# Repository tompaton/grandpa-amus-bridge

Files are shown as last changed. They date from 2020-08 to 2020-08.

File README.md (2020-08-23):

## grandpa-amus-bridge

Model of the traditional Chinese bridge constructed by Grandpa Amu

# Grandpa Amu's Bridge

I found this traditional Chinese bridge design and construction
captivating.  The interlocking pieces mean that no fasteners or glue
is required and it gets stronger under load.

[Construction video](https://www.youtube.com/watch?v=PYkgEf3eWqA) and
[more, because who can get enough?](https://www.youtube.com/watch?v=iSPAK3mcI3c)

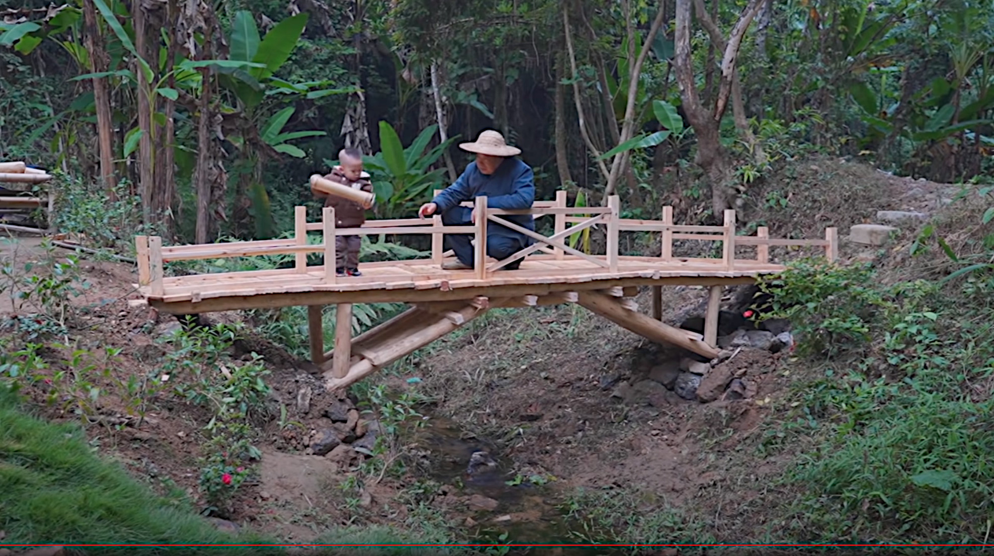
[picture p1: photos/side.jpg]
Bridge from the side


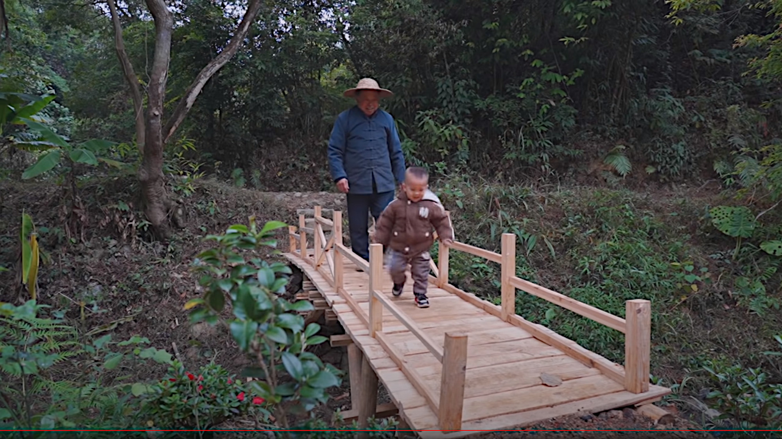
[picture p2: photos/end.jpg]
Bridge from the emd


## CAD model

First I created a CAD model using
[DeclaraCAD](https://declaracad.com/).

[bridge.enaml source](https://github.com/tompaton/grandpa-amus-bridge/blob/master/src/bridge.enaml)

This worked pretty well as there are lots of repeated parts, and by
using the `Cut` operation, mortises could be automatically created in
exactly the right locations for the tenons.

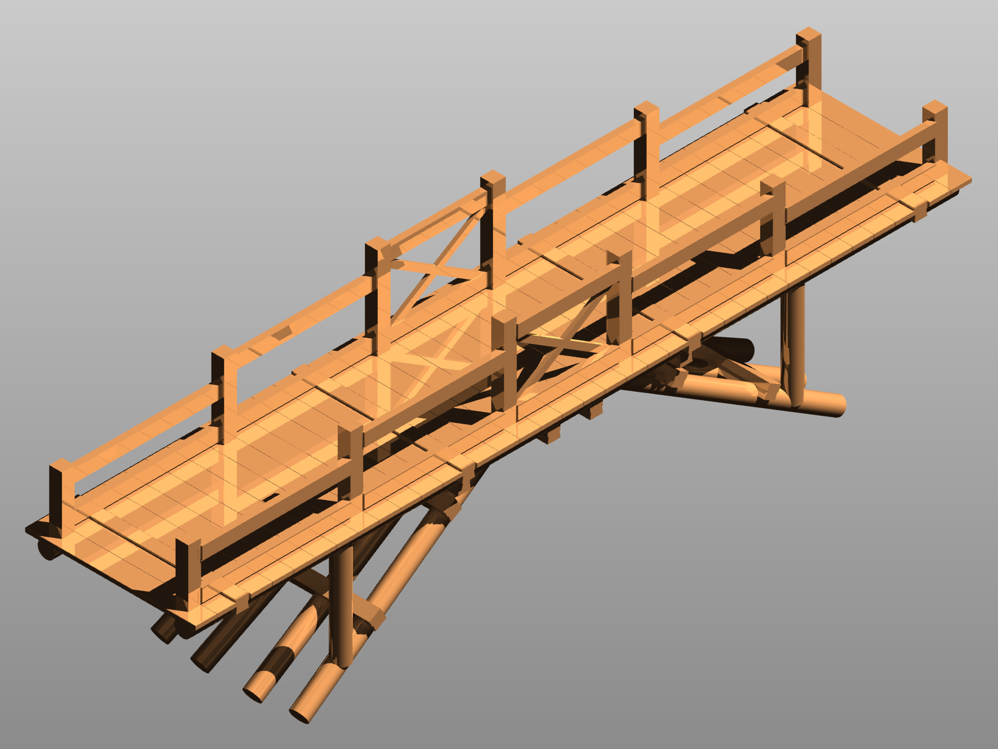
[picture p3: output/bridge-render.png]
Rendered CAD model


Transparency helps see the structure and joints:

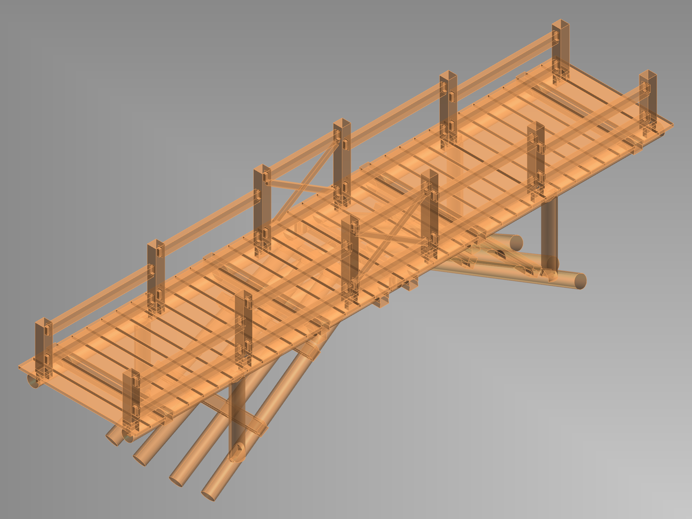
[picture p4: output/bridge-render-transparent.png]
Transparent render


I was able to export a [bridge.step](output/bridge.step) file which
could be imported into [FreeCAD](https://www.freecadweb.org/) to
generate a drawing.

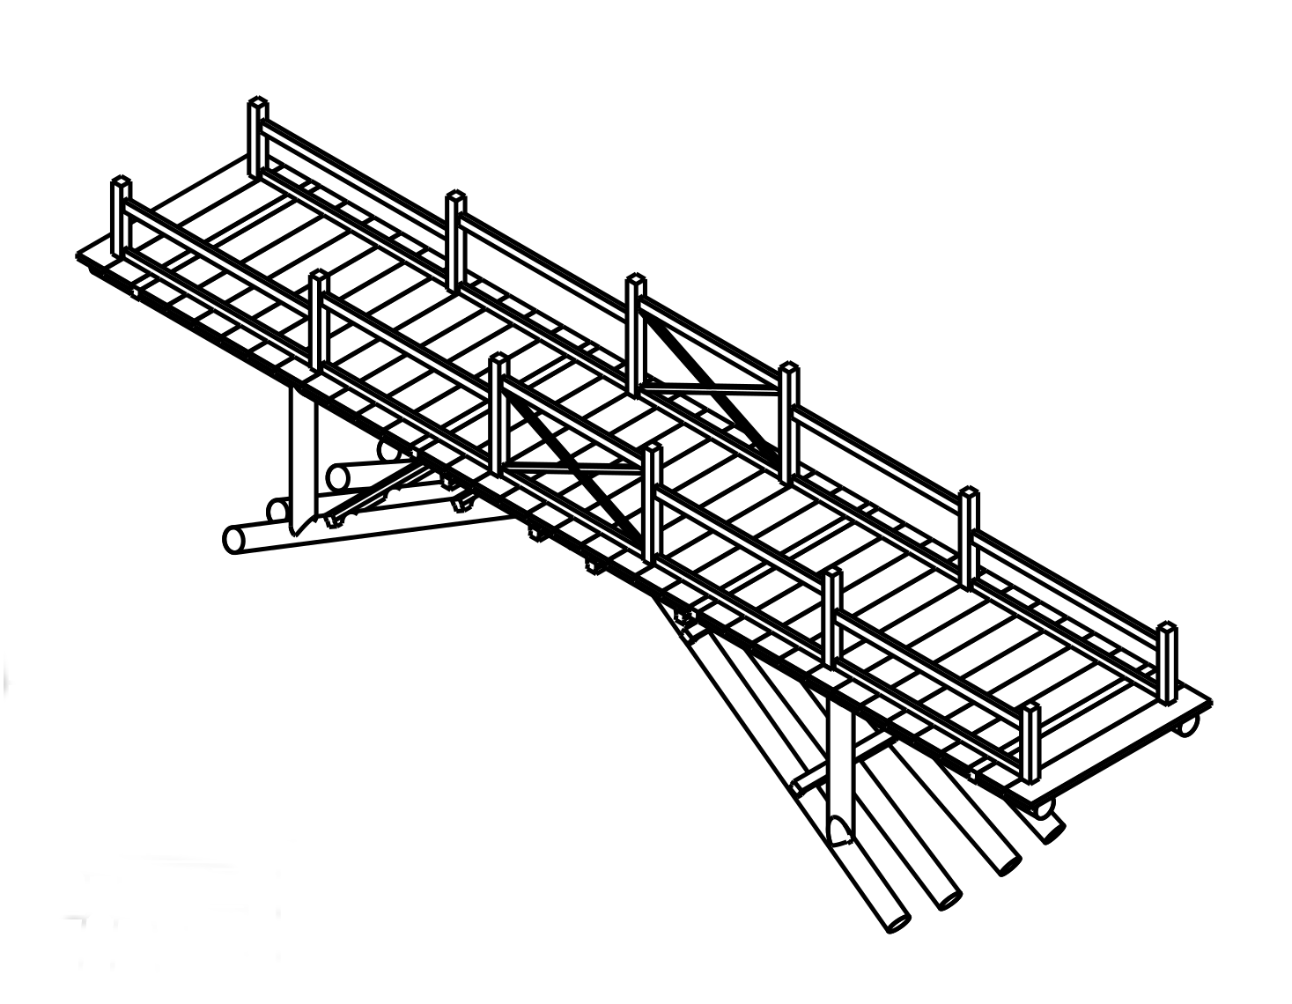
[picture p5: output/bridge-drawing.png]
Technical drawing detail


[Full page drawing](output/bridge-drawing.pdf) with other elevation views.

And after converting that to
[bridge.stl](https://github.com/tompaton/grandpa-amus-bridge/blob/master/output/bridge.stl)
it should be viewable in 3D everywhere.

## Scale model

Even though I created the CAD model and drawings, construction was
done by eye.

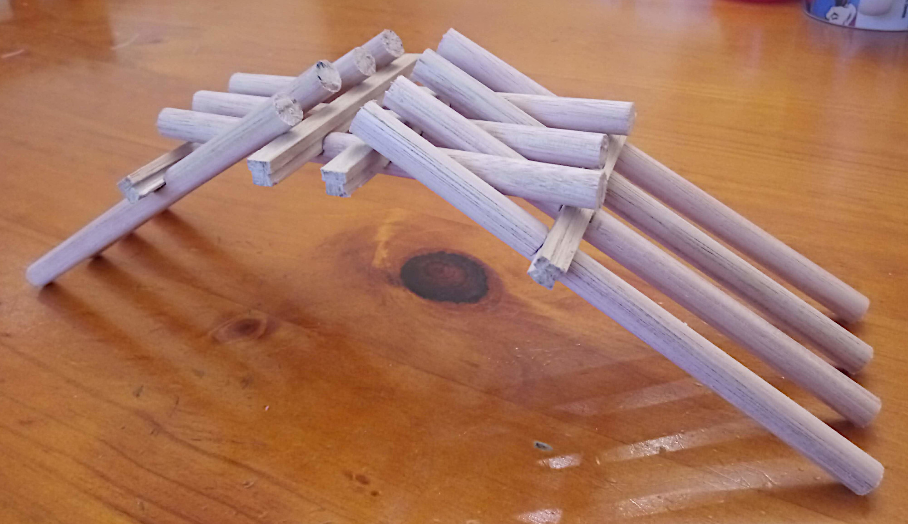
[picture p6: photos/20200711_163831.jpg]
First steps

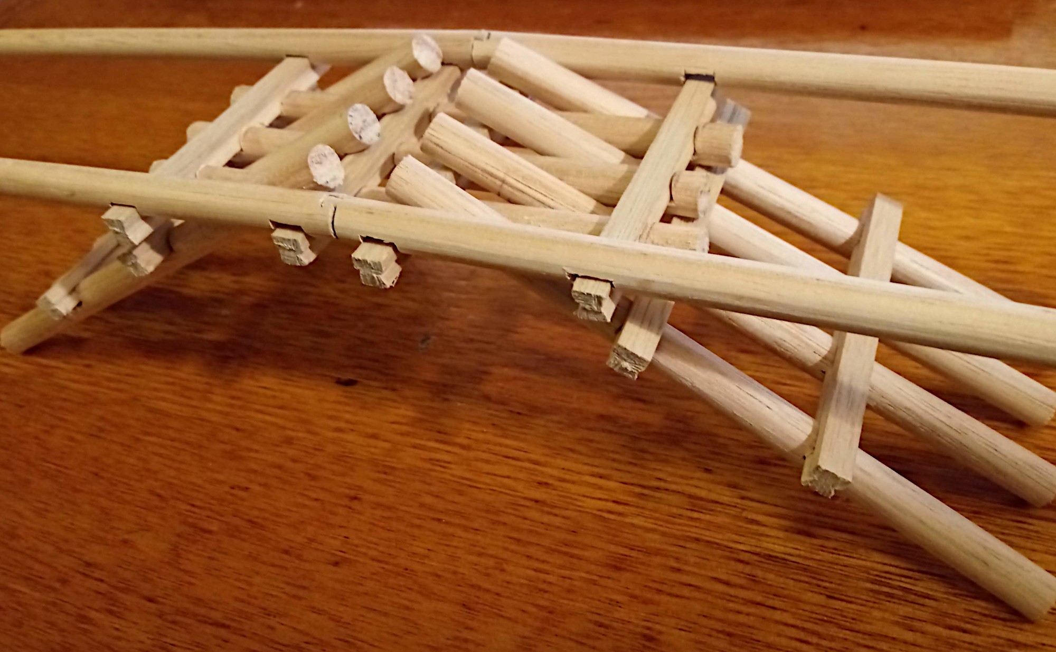
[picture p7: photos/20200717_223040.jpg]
Base structure

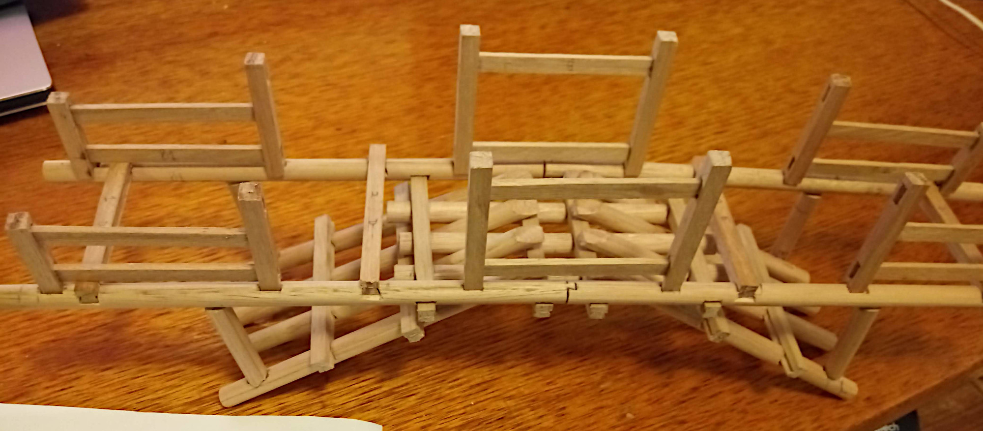
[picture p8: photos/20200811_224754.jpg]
Side rails

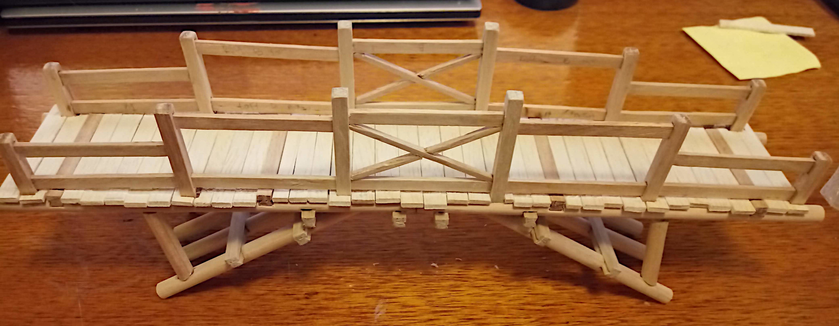
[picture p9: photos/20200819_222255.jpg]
Final assembly


The final model would hold together without glue, but it's a bit
fragile that way and I've spent enough time assembling it, so I glued
it with PVA craft glue.

It was then finished with a few coats of shellac.

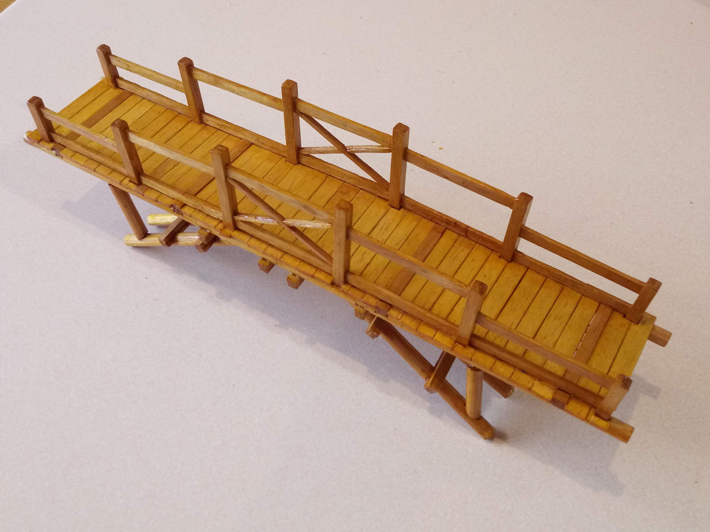
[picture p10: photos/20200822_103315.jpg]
Finished bridge model

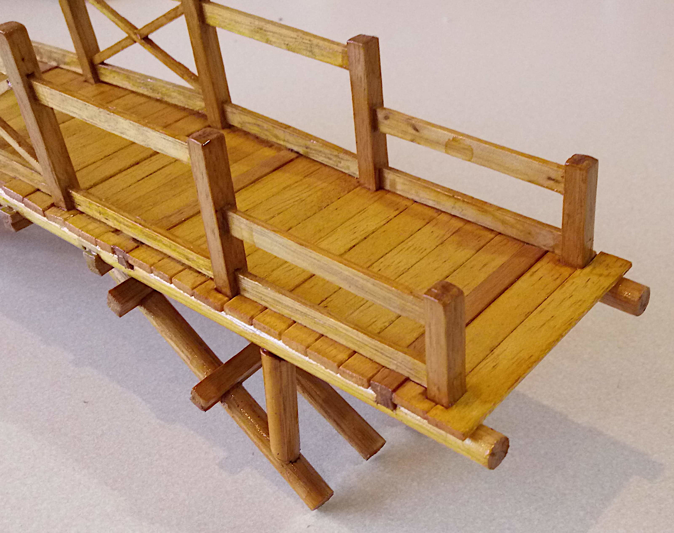
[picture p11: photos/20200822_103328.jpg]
Detail

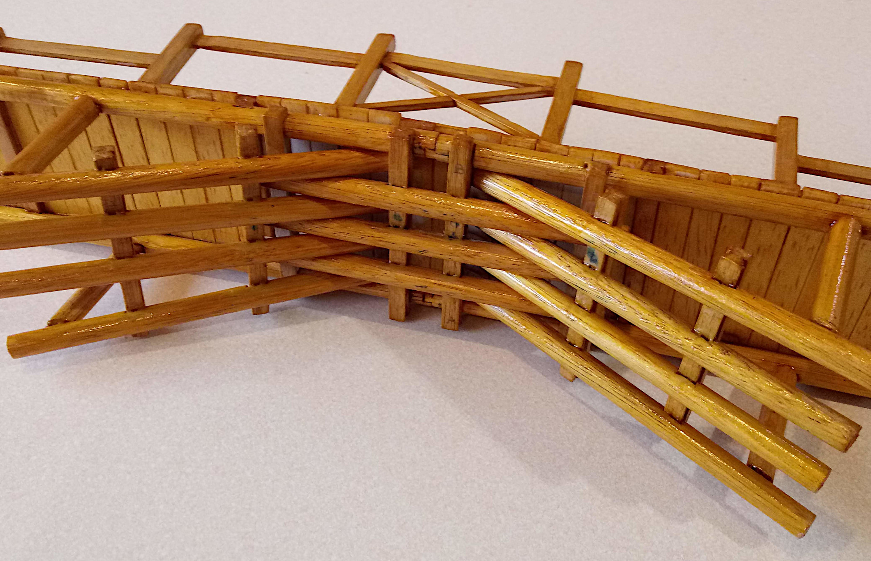
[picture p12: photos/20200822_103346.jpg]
Underside detail


### Tools & Materials

* Craft knife
* Mini-hacksaw
* Sandpaper

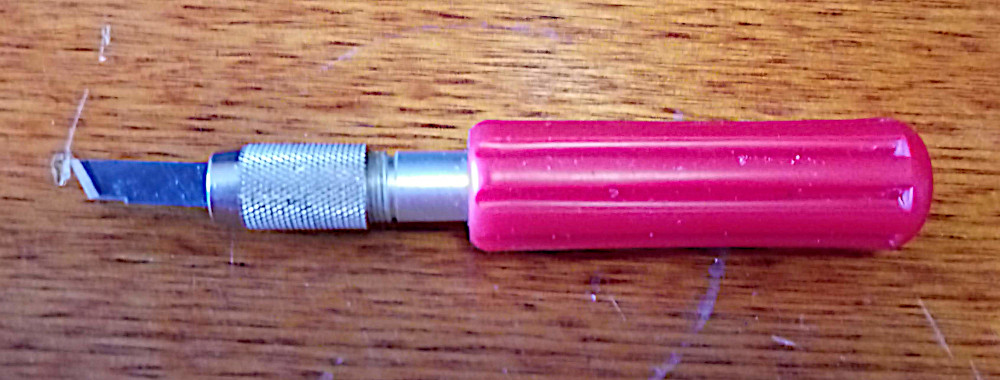
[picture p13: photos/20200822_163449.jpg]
Craft knife


* 8mm x 1200mm Tasmanian oak round dowel (2 pieces)
* 6mm x 6mm x 1200mm Tasmanian oak dressed all round moulding (2 pieces)
* 2.5mm x 100mm x 915mm balsa sheet (1/3 of a piece)

I cut mortises with the craft knife when it would have been more
sensible to make a jig to drill out mortise holes.

Rails were created by splitting the square dowel.

There wasn't much waste, probably about 20mm left from each of the
round and square dowels.

## Next steps?

* 3D printed plastic model
* Paper model

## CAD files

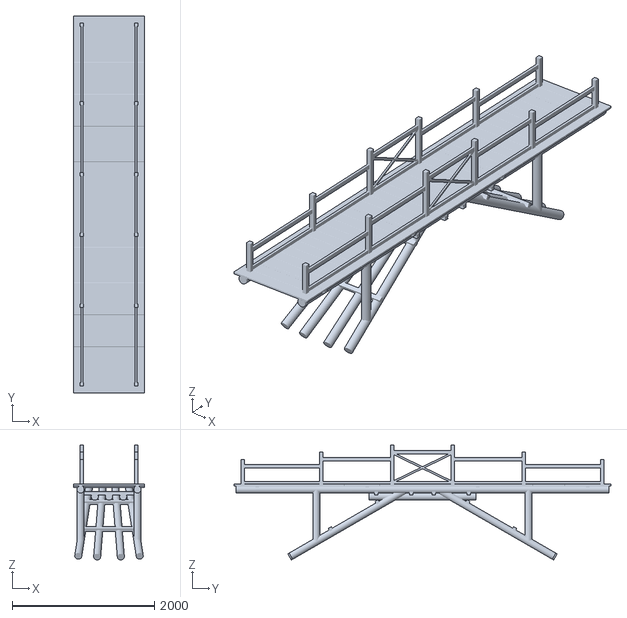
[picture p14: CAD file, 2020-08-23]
output/bridge.stl
1000.0 x 5300.0 x 1615.7

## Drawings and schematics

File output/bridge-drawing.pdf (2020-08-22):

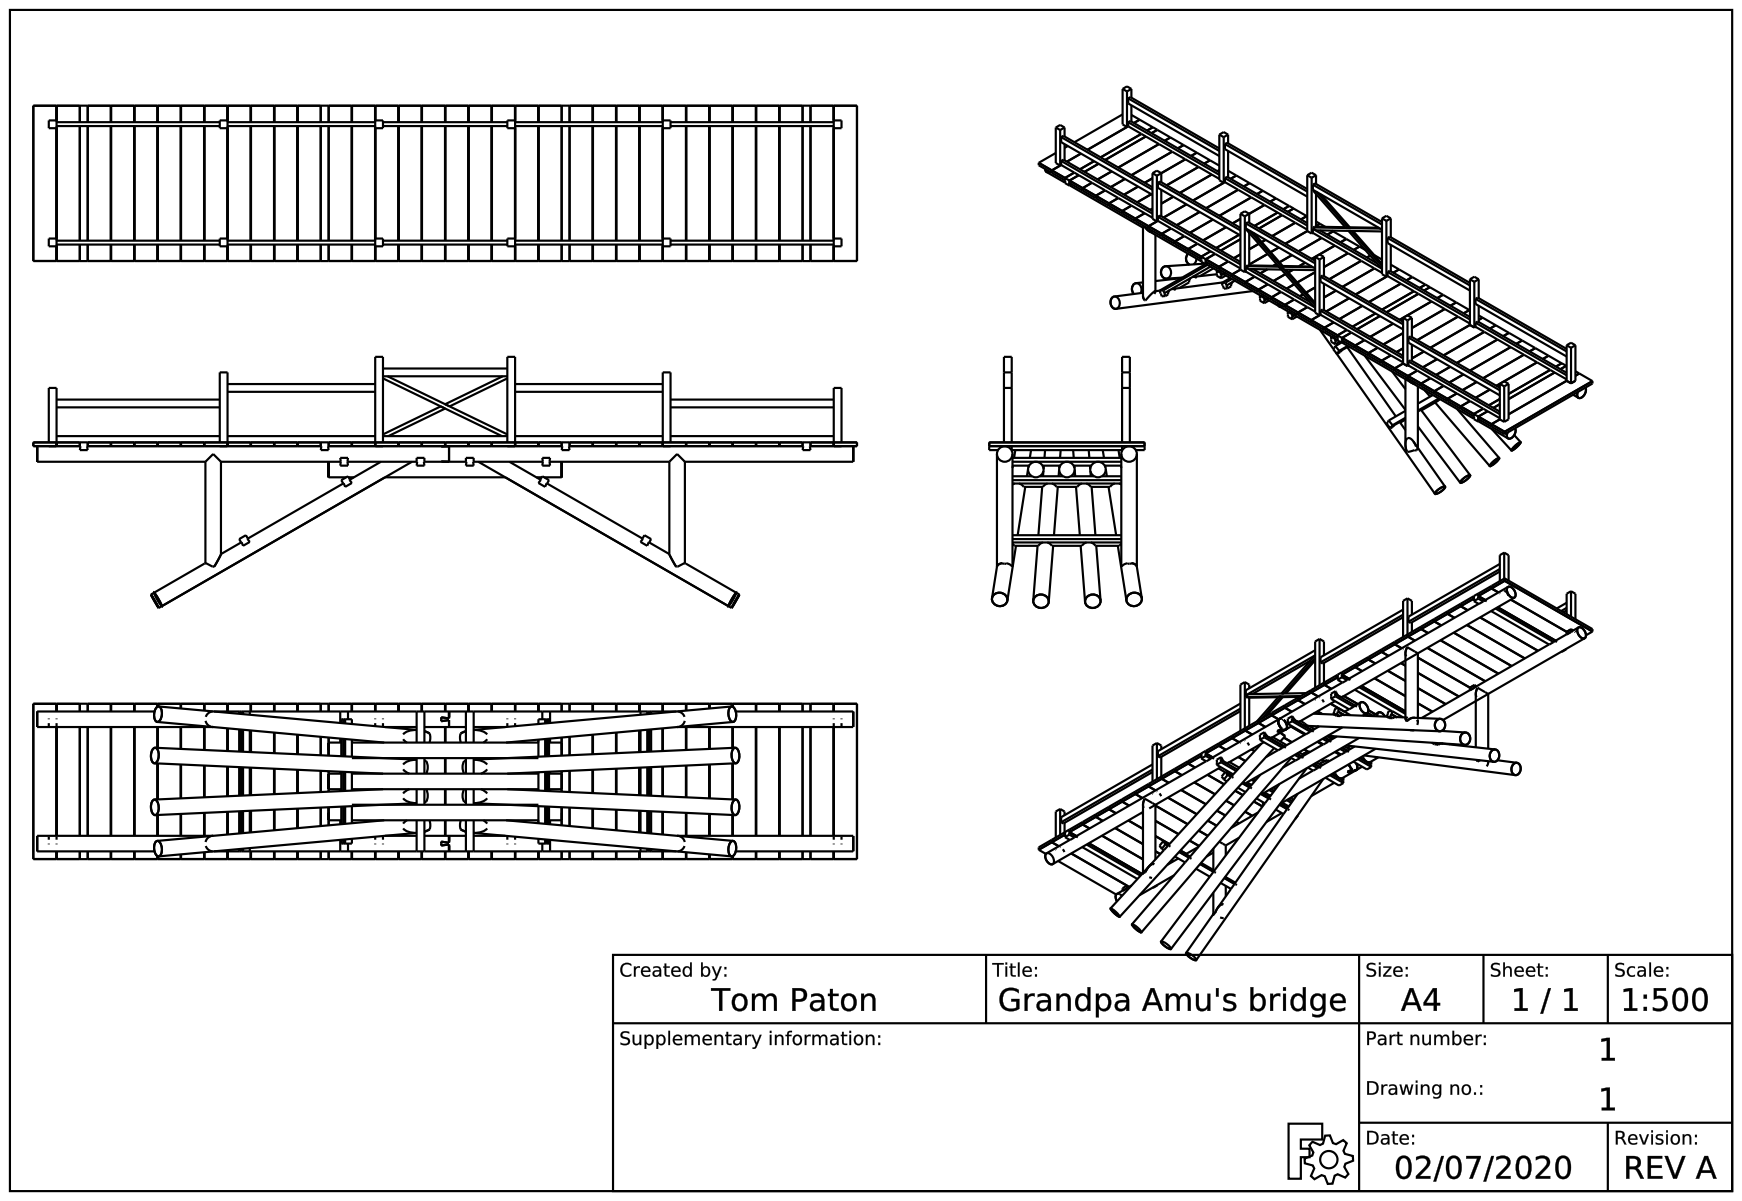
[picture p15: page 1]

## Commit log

2020-08-22 add cad drawings and rendered images
2020-08-23 add frames grabbed from youtube video
2020-08-23 add bridge.stl
    [bridge.stl]
2020-08-23 add bridge.stl to writeup
2020-08-23 can't embed .stl :(
